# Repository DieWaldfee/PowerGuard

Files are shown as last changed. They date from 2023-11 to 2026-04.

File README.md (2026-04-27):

# PowerGuard
PowerGuard-Platine und Software zur Sicherheitsüberwachung einer Heizstabsteuerung

**zugehörige Repositories**<br>
- PowerGuard (dieses Repository)
- Heizstabsteuerung (Steuerungsplatine <a href="https://github.com/DieWaldfee/Heizstabsteuerung"> Link </a>)
- Heizstab_ioBroker (Ansteuerungs-Blockly - ein MQTT-Broker wird benötigt - Link)

**Funktion:** <br>
Der ESP32 steuert 2 Temperatursensoren (DS18B20) an und liest diese aus. Die beiden Sensoren sollen am höchsten Punkt des Pufferspeichers der Heizung angebracht werden, in dem auch der elektrische Heizstab eingeschraubt ist. 
Die beiden Werte werden einerseits verglichen und andererseits benutzt, um die Pufferspeichertemperatur zu überwachen. Liegt die Temperatur zu hoch, dann ist zu viel Energie im Pufferspeicher und vermutlich ist der Heizstab dafür ursächlich -> der Heizstabsteuerung wird der Strom abgeschalten. Dies stellt eine unabhängige Sicherungsfunktion dar, das jedweder Fehler im Heizstabsystem behandelt und die Anlage in den sicheren Zustand überführt (d.h. aus).<p>
Der PowerGuard hat 2 Möglichkeiten dies zu tun: <br>
(1) die 5V Versorgung des ESP32 der Heizstabsteuerung abzuschalten -> die Relais werden nicht mehr angesteuert - unabhängig vom Fehlerbild. <br>
(2) die 12V Versorgungsspannung der Lastschaltrelais (SSR siehe Heizstabsteuerung) wird abgeschaltet -> die Heizstabsteuerung bleibt aktiv, kann aber nichts mehr schalten. <p>
Die Kommunikation mit dem ESP32 wird über WiFi abgewickelt und über das Protokoll MQTT umgesetzt. Es stehen mehrere Befehle zur Verfügung, die ebenfalls via MQTT an den ESP gesendet werden kann. Neben "restart" / "reboot" (führt zu einem Neustart des ESP32) kann die ganze Konfiguration und der debug-Level angepasst werden. Alle Anpassungen sind nach einem Neustart verloren, da diese nicht permanent gespeichert werden. Befehle werden unter der MQTT-Hierarchie in folgendem Ort empfangen: `SmartHome/Keller/Heizung/ESP32_PowerGuard/command` (MQTT_SERIAL_RECEIVER_COMMAND)

**Entwicklungsumgebungen:** <br>
Die aktuelle Software (V2.x) für den ESP32 wird mit **PlatformIO** entwickelt (z. B. in VS Code mit dem PlatformIO-Plugin). Die Konfiguration des Projekts befindet sich in der Datei `platformio.ini`; Compilieren und Flashen erfolgen direkt über PlatformIO.<br>
Die historische Erstversion (V1.0) wurde in der **Arduino-IDE** erstellt und ist im Unterordner `V1.0/` archiviert.<br>
Die Platine (PCB) habe ich in Eagle von AutoCAD modelliert. Für Maker gibt es eine kostenfreie Version. Die CAM-Daten (PCB-Produktionsdaten), sowie die BOM (Stückliste) sind ebenfalls aus Eagle ausgegeben.
Eine Übersichtsversion der Platine ist mit Fritzing umgesetzt und enthält auch einige Notizen zur Pinbelegung.<br>

**benötigte Umgebung:** <br>
- ioBroker zur Ansteuerung (geht natürlich auch mit anderen SmartHome-Systemen, solange diese MQTT sprechen können)
- ioBroker MGTT-Adapter
- MQTT-Broker: z.B. mosquitto unter Linux/Debian/Raspian...
- 230V Stromversorgung oder alternativ eine 5V Versorgung über z.B. ein USB-Ladegerät (muss 2 ESP32 sicher versorgen können -> 2A reicht völlig aus) oder über die Schraubklemmen anderweitig versorgt.

### Abhängigkeiten (PlatformIO / `platformio.ini`):
OneWire:_______________PaulStoffregen/OneWire (git-master) – v2.3.7 inkompatibel mit ESP-IDF 5.x; v2.3.8 buggy<br>
DallasTemperature:_____milesburton/DallasTemperature v4.0.4<br>
PubSubClient:__________knolleary/PubSubClient v2.8<br>
WiFi.h / esp_task_wdt:_Espressif Arduino-Framework (via pioarduino platform-espressif32)<br>

### Board / Plattform (PlatformIO):
platform: pioarduino platform-espressif32 v55.03.38-1 (ESP-IDF 5.x)<br>
board: esp32dev<br>
framework: arduino<br>

**Hardware-Version (PCB V1.0 vs. V2.0):**<br>
In `platformio.ini` kann die Hardware-Version über ein Build-Flag gesetzt werden:<br>
```
build_flags = -DHARDWARE_VERSION=2   ; für PCB V2.0 (mit MSG-LED an Pin 22)
```
Ohne Build-Flag wird V1.0-Verhalten angenommen (kein MSG-LED, Blink auf OK-LED).<br>

| PIN | V1.0 | V2.0 |
|-----|---|---|
| 19  | LED OK (grün) | LED OK (grün) |
| 22  | – | LED MSG (gelb) |
| 23  | LED ERROR (rot) | LED ERROR (rot) |
| 25  | DS18B20 OneWire Bus | DS18B20 OneWire Bus |
| 32  | PHASE 5V (Heizstabsteuerung) | PHASE 5V (Heizstabsteuerung) |
| 18  | PHASE 12V (SSR-Relaisversorgung) | PHASE 12V (SSR-Relaisversorgung) |

**aktuelle Versionen:** <br>
- ESP-Software    V2.x (PlatformIO, `src/PowerGuard.cpp`)
- ESP-Software    V1.0 (Arduino IDE, archiviert in `V1.0/PowerGuard.ino`)
- PCB (Eagle) 	   V2.0
- CAM             V1.0
- BOM             V1.0
- Fritzing		      V1.1
 
Fokus der PCB V2.0 ist die Platine mit über einen PCB-Hersteller umzusetzen.
Die CAM-Datei ist passend für https://jlcpcb.com. Stand 03.11.2023 ist die Platine für 2$ (5 St.) bestellbar.
In der BOM findet sich die Stückliste für die Bestückung wieder.



Zugehöriges Projekt: https://github.com/users/DieWaldfee/projects/1

**Installation:**
* Zugangsdaten in `/src/secrets.h` eintragen (Hostname, WLAN-SSID, WLAN-Passwort, MQTT-Server, MQTT-Port, MQTT-User, MQTT-Passwort)
* Hardware-Version in `platformio.ini` als Build-Flag setzen (`-DHARDWARE_VERSION=2` für PCB V2.0, weglassen für V1.0)
* MQTT-Pfade sind in `src/PowerGuard.cpp` als `#define` hinterlegt und können dort angepasst werden<br>
&nbsp;&nbsp;&nbsp;
* Debug-Level kann via MQTT-Befehl `debug=0` … `debug=3` zur Laufzeit gesetzt werden (0 = Boot only; 1 = Basic; 2 = Advanced; 3 = Absolut); alternativ im Quellcode in Zeile 14 von `src/PowerGuard.cpp`
* ESP-Software wird über PlatformIO compiliert und auf das „ESP32 Dev Kit V4" geflasht.
* Platine entweder via Eagle an PCB-Hersteller übermitteln, oder das fertige CAM-File über die Anbieter-Webseite senden. (z.B. an https://jlcpcb.com)
* Platine bestücken + ESP und Level-Shifter (3.3V <-> 5V) aufsetzen.
* Relais anschließen.
* 12V Versorgung der Heizstabsteuerung wird über LED-Treiber realisiert.

### MQTT-Steuerbefehle

Befehle werden auf dem Topic **`SmartHome/Keller/Heizung/ESP32_PowerGuard/command`** empfangen.<br>
Bestätigungen erscheinen auf **`SmartHome/Keller/Heizung/ESP32_PowerGuard/ac`**.

| Befehl | Beschreibung | Antwort (ac-Topic) |
|---|---|---|
| `Test` | Verbindungstest | `Test OK` |
| `debug=0` … `debug=3` | Debug-Level setzen (0=Boot only, 1=Basic, 2=Advanced, 3=Absolut) | `debug=X umgesetzt` |
| `panicMode=0` | Panic-Modus zurücksetzen; Heizstabsteuerung neu starten (wenn thermalLimit=0) | `panicMode=0 umgesetzt` |
| `panicMode=1` | Panic-Abschaltung auslösen (5V + 12V aus) | `panicMode=1 umgesetzt` |
| `hardwareError=0` | Hardware-Fehler-Flag zurücksetzen | `hardwareError=0 umgesetzt` |
| `hardwareError=1` | Hardware-Fehler setzen → Panic-Abschaltung | `hardwareError=1 umgesetzt` |
| `thermalLimit=0` | Thermisches Limit zurücksetzen; Heizstabsteuerung neu starten (wenn panicMode=0 und hardwareError=0) | `thermalLimit=0 umgesetzt` |
| `thermalLimit=1` | Thermische Abschaltung auslösen (12V aus) | `thermalLimit=1 umgesetzt` |
| `tempLimit=<Wert>` | Abschalttemperatur 12V [°C] (Standard: 90,0) | `tempLimit=<Wert> umgesetzt` |
| `tempMaxLimit=<Wert>` | Panic-Abschalttemperatur 5V+12V [°C] (Standard: 95,0) | `tempMaxLimit=<Wert> umgesetzt` |
| `tempReconnect=<Wert>` | Wiedereinschalttemperatur [°C] (Standard: 80,0) | `tempReconnect=<Wert> umgesetzt` |
| `deltaT=<Wert>` | Max. zulässige Differenz zwischen den beiden Sensoren [K] (Standard: 2,0) | `deltaT=<Wert> umgesetzt` |
| `minTemp=<Wert>` | Untere Plausibilitätsgrenze [°C] (Standard: 10,0) | `minTemp=<Wert> umgesetzt` |
| `maxTemp=<Wert>` | Obere Plausibilitätsgrenze [°C] (Standard: 100,0) | `maxTemp=<Wert> umgesetzt` |
| `restart` oder `reboot` | ESP32 neu starten (Ausgänge werden vorher abgeschaltet) | `reboot in einer Sekunde!` |

> **Hinweis:** Alle Parameteränderungen sind flüchtig und gehen nach einem Neustart verloren.

### MQTT-Statustopics (veröffentlicht, alle 60 s)

Basis-Pfad: `SmartHome/Keller/Heizung/ESP32_PowerGuard/`

| Topic (relativ zum Basis-Pfad) | Inhalt | Retain |
|---|---|---|
| `status` | Online-Status: `true` / `false` (LWT) | ja |
| `ac` | Befehlsbestätigungen | nein |
| `error` | Fehlermeldungen / Reconnect-Infos | ja |
| `Temperatur/0/JSON` | Sensor 0 komplett als JSON | nein |
| `Temperatur/0/Temperatur` | Temperatur Sensor 0 [°C] | nein |
| `Temperatur/0/ID` | Sensor-Index 0 | nein |
| `Temperatur/0/Adresse` | 1-Wire-Adresse Sensor 0 | nein |
| `Temperatur/0/Ort` | Ortsbezeichnung Sensor 0 | nein |
| `Temperatur/1/…` | Gleiche Subtopics für Sensor 1 | nein |
| `state/JSON` | Systemzustand komplett als JSON | nein |
| `state/panicMode` | Panic-Mode Flag (0/1) | nein |
| `state/thermalLimit` | Thermal-Limit Flag (0/1) | nein |
| `state/hardwareError` | Hardware-Fehler Flag (0/1) | nein |
| `state/lastError` | Letzter Fehler als Klartext | nein |
| `state/WiFi_Signal_Strength` | WiFi-Signalstärke [dBm] | nein |
| `state/WiFi_IP_Adress` | IP-Adresse | nein |
| `state/WiFi_MAC_Adress` | MAC-Adresse | nein |
| `config/JSON_0` | Konfigurationsparameter als JSON | nein |

**Bezugsquellen:**
* Platinennetzteil AC-05-3    <a href="https://www.azdelivery.de/products/copy-of-220v-zu-5v-mini-netzteil"> AZ-Delivery </a>
* Levelshifter (3.3V <-> 5V)  <a href="https://www.amazon.de/RUNCCI-YUN-Pegelwandler-Converter-BiDirektional-Mikrocontroller/dp/B082F6BSB5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"> Amazon </a>
* Relais <a href="https://www.amazon.de/gp/product/B0B5816YJ7/ref=ppx_yo_dt_b_search_asin_image?ie=UTF8&th=1"> Amazon </a> oder <a href="https://www.az-delivery.de/products/relais-modul"> AZ Delivery </a>
* 12V LED-Treiber als Schaltspannung der SSR-Relais  <a href="https://www.amazon.de/gp/product/B082NLNCSB/ref=ppx_yo_dt_b_search_asin_image?ie=UTF8&psc=1"> Amazon </a>
* JST-Buchse <a href="https://www.amazon.de/gp/product/B0B2R99X99/ref=ppx_yo_dt_b_search_asin_title?ie=UTF8&psc=1"> Amazon </a>
* Klemmbuchse <a href="https://www.amazon.de/gp/product/B087RN8FDZ/ref=ppx_yo_dt_b_search_asin_title?ie=UTF8&th=1"> Amazon </a>
* Widerstände 4,7kOhm, 220 Ohm, 330 Ohm, Led grün, gelb und rot Amazon / eBay / Conrad...
* Temperatursensoren DS18B20 <a href="https://www.az-delivery.de/products/2er-set-ds18b20-mit-3m-kabel"> AZ Delivery </a>

**fertige Platine:**

grafik

grafik
(oberes Relais steuert +5V -> Heizstabsteuerung; unteres Relais steuert die 12V für die SSR-40-DA Lastschaltrelais)

**Haftungsausschluss**<br>
Deutsch: Dieses Projekt arbeitet mit Netzspannung (220 V) und darf ausschließlich von qualifiziertem Fachpersonal aufgebaut, installiert und betrieben werden. Durch die anliegende Spannung besteht Lebensgefahr! Fehler in Schaltung oder Software können zu Sachschäden (z. B. an Gebäude oder Heizung) oder zu gefährlichen Situationen für Leib und Leben führen. Nutzung auf eigene Gefahr – jegliche Haftung wird ausgeschlossen.
<br>
English: This project operates with mains voltage (220 V) and must only be assembled, installed, and operated by qualified professionals. The present voltage poses a risk of fatal electric shock! Errors in circuitry or software may cause property damage (e.g., to buildings or heating systems) or create life-threatening situations. Use at your own risk – any liability is disclaimed.

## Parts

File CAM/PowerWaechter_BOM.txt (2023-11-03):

Stückliste PowerGuard 03.11.2023 15:11

Part    Value                    Device                   Package                  Description                                         AVAILABILITY CHECK_PRICES                                                                     DESCRIPTION                                                MF                                                                                         MP                MPN           OC_FARNELL OC_NEWARK PACKAGE POPULARITY PRICE PURCHASE-URL                                           SNAPEDA_LINK SPICEPREFIX                                                                      
CON1    JST-XH-03                JST-XH-03                JST-XH-03                                                                                                                                                                                                                                                                                                                                                                                                                                                                                                                                                           
CON2    JST-XH-03                JST-XH-03                JST-XH-03                                                                                                                                                                                                                                                                                                                                                                                                                                                                                                                                                           
CON3                             WAGO-500-2               WAGO-500-2               WAGO SCREW CLAMP                                                                                                                                                                                                                                                                                                          237-102       unknown    70K9898           32                                                                                                                                                                    
CON4                             WAGO-500-2               WAGO-500-2               WAGO SCREW CLAMP                                                                                                                                                                                                                                                                                                          237-102       unknown    70K9898           32                                                                                                                                                                    
JP1                              JP4E                     JP4                      JUMPER                                                                                                                                                                                                                                                                                                                                                               15                                                                                                                                                                    
LED1    rot                      LED3MM                   LED3MM                   LED                                                                                                                                                                                                                                                                                                                                                                  97                                                                                                                                                                    
LED2    grün                     LED3MM                   LED3MM                   LED                                                                                                                                                                                                                                                                                                                                                                  97                                                                                                                                                                    
LED3    gelb                     LED3MM                   LED3MM                   LED                                                                                                                                                                                                                                                                                                                                                                  97                                                                                                                                                                    
LS_SSR1 LEVELSHIFTER             LEVELSHIFTER             LEVELSHIFTER             Logic Level Converter - Bi-Direc Check availability In Stock                                                                                       BSS138 Logic-Level Translator Interface Evaluation Board  SparkFun                                                                                   BOB-12009                                            None               None  https://pricing.snapeda.com/search?q=BOB-12009&ref=eda                                                                                               
POWER1  AC-05-3                  AC-05-3                  AC-05-3                  AC-05-3                                                                                                                                                                                                                                                                                                                                                                                                                                                                                                                                    
R1      220                      R_10MM0207/10            0207/10                  RESISTOR, European symbol                                                                                                                                                                                                                                                                                                                                            81                                                                                   R                                                                                
R2      330                      R_10MM0207/10            0207/10                  RESISTOR, European symbol                                                                                                                                                                                                                                                                                                                                            81                                                                                   R                                                                                
R3      220                      R_10MM0207/10            0207/10                  RESISTOR, European symbol                                                                                                                                                                                                                                                                                                                                            81                                                                                   R                                                                                
R4      4.7 k                    R_10MM0207/10            0207/10                  RESISTOR, European symbol                                                                                                                                                                                                                                                                                                                                            81                                                                                   R                                                                                
U1      ESP32-DEV-KIT-V4         ESP32-DEV-KIT-V4         ESP32-DEV-KIT-V4         ESP32-DEVKITC Check availability                    In Stock     https://www.snapeda.com/parts/ESP32-DEVKITC/Espressif+Systems/view-part/?ref=eda  ESP32-WROOM-32UE series Transceiver                        802.11 b/g/n (Wi-Fi, WiFi, WLAN), Bluetooth ® Smart Ready 4.x Dual Mode Evaluation Board  Espressif Systems ESP32-DEVKITC                              None             None                                                                https://www.snapeda.com/parts/ESP32-DEVKITC/Espressif+Systems/view-part/?ref=snap

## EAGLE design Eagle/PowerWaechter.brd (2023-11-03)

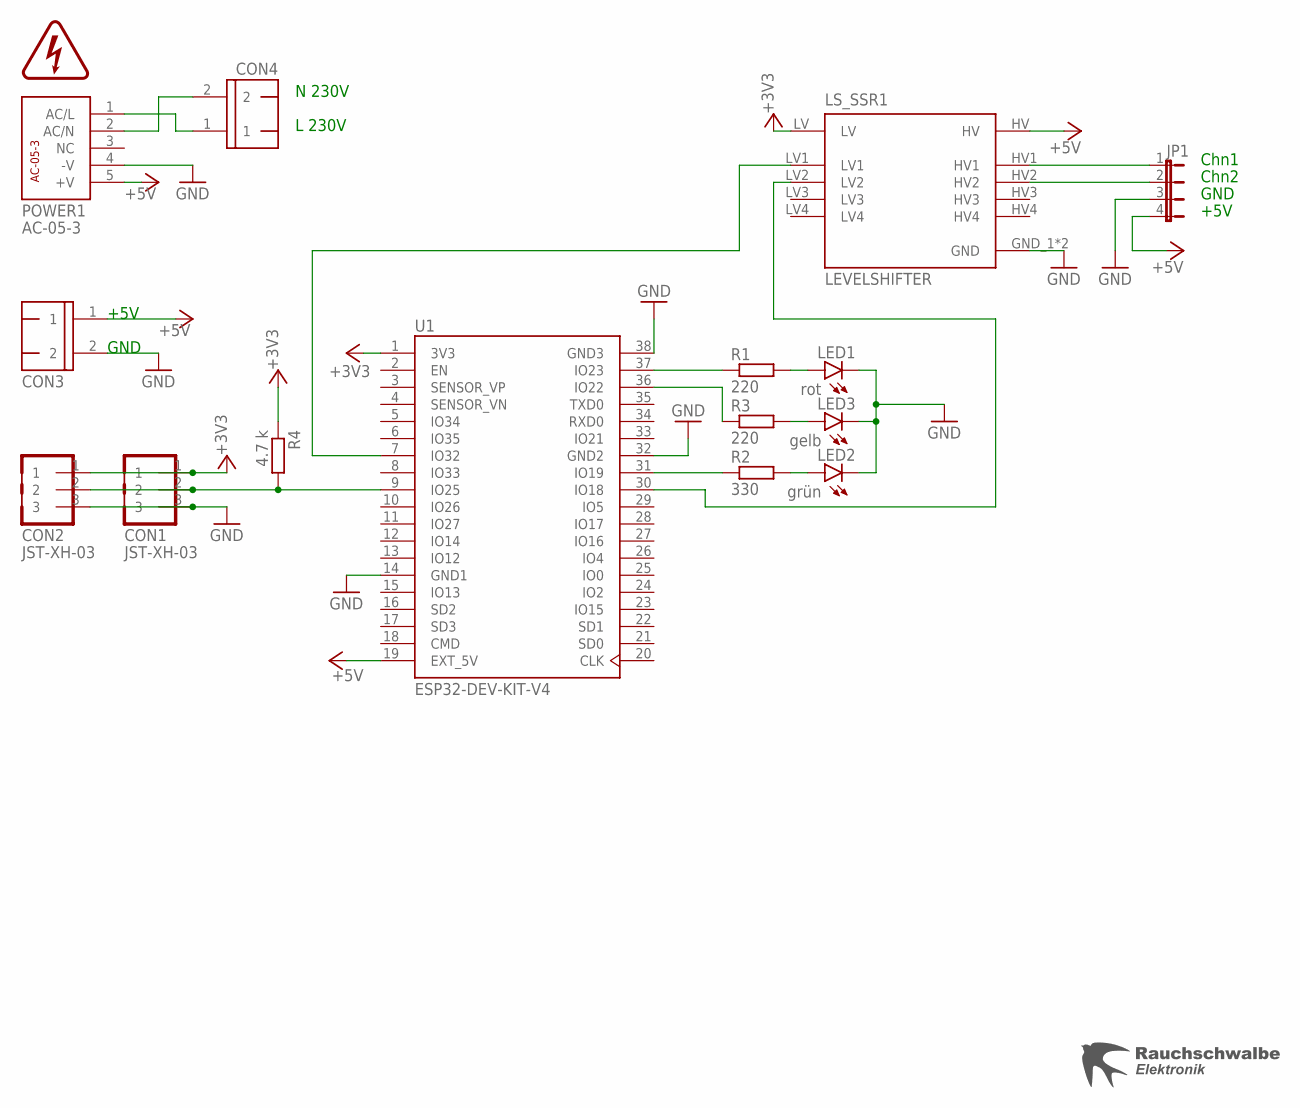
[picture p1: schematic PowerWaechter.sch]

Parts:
CON1, CON2: JST-XH-03
CON3, CON4: WAGO-500-2
JP1: JP4E; JP4
LED1: rot; LED3MM
LED2: grün; LED3MM
LED3: gelb; LED3MM
LS_SSR1: LEVELSHIFTER
POWER1: AC-05-3
R1, R3: 220; 0207/10
R2: 330; 0207/10
R4: 4.7 k; 0207/10
U1: ESP32-DEV-KIT-V4
U$1: WARNLABLE_BLITZ_KLEIN
U$2: LOGO_RAUCHSCHWALBE_KLEIN

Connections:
+3V3: CON1.1, CON2.1, LS_SSR1.LV, R4.1, U1.1 (3V3)
+5V: CON3.1, JP1.4, LS_SSR1.HV, POWER1.5 (+V), U1.19 (EXT_5V)
GND: CON1.3, CON2.3, CON3.2, JP1.3, LED1.K (C), LED2.K (C), LED3.K (C), LS_SSR1.GND_1 (GND), LS_SSR1.GND_2 (GND), POWER1.4 (-V), U1.14 (GND1), U1.32 (GND2), U1.38 (GND3)
unnamed: R1.1, U1.37 (IO23)
unnamed: LED3.A, R3.2
unnamed: R2.1, U1.31 (IO19)
unnamed: LED1.A, R1.2
unnamed: LED2.A, R2.2
unnamed: R3.1, U1.36 (IO22)
unnamed: LS_SSR1.LV1, U1.7 (IO32)
unnamed: CON1.2, CON2.2, R4.2, U1.9 (IO25)
unnamed: LS_SSR1.LV2, U1.30 (IO18)
unnamed: JP1.1, LS_SSR1.HV1
unnamed: JP1.2, LS_SSR1.HV2
PHASE_L: CON4.1, POWER1.1 (AC/L)
PHASE_N: CON4.2, POWER1.2 (AC/N)

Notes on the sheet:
GND
+5V
Chn1
Chn2
L 230V
N 230V

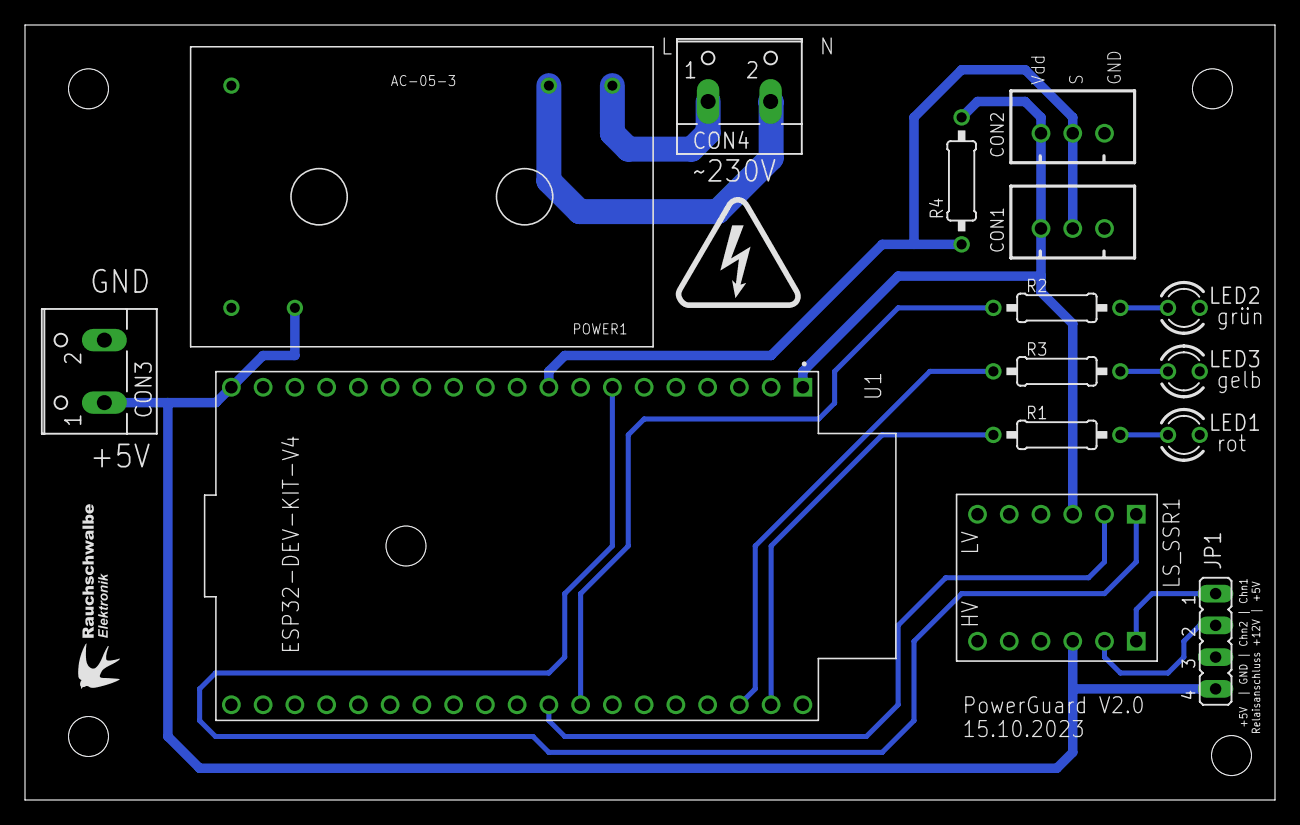
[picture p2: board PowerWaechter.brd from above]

Board: 2 copper layers, 100.0 x 62.0 mm, 17 parts (0 on the bottom side), 16 nets.

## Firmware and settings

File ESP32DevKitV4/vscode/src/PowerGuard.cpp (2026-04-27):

//https://beelogger.de/sensoren/temperatursensor-ds18b20/ für Pinning und Anregung
#include <OneWire.h>
#include <DallasTemperature.h>
#include <WiFi.h>
#include <WiFiClient.h>
#include <PubSubClient.h>
#include <esp_task_wdt.h>
#include "secrets.h"

#define LED_ERROR 23
#define LED_MSG 22
#define LED_OK 19
#define ONE_WIRE_BUS 25
static byte debug = 0;
static String lastError = "";

//Sicherheitsfunktionen
int volatile hardwareError = 0; // Indikator, ob ein Sensordefekt erkannt wurde.
int volatile thermalLimit = 0;  // Indikator, das die maximale Temperatur am Top-Sensor. Phasen werden abgeschalten.
int volatile panicMode = 0;     // Indikator für die Zwangsabschaltung - ab jetzt wird nichts mehr zugeschaltet

//Schaltausgaenge für Phase 1-3 und Luefter
#define PHASE_5V 32             // Steuerpin für Phase 5V Versorgung zum ESP32 Heizstabsteuerung
#define PHASE_12V 18            // Steuerpin für Phase 12V Versorgung zum ESP32 Heizstabsteuerung

// Definition der Zugangsdaten WiFi
WiFiClient myWiFiClient;

//Definition der Zugangsdaten MQTT
#define MQTT_CLIENTID "ESP32_PowerGuard" //Name muss eineindeutig auf dem MQTT-Broker sein!
#define PG_MQTT_KEEPALIVE 90
#define PG_MQTT_SOCKETTIMEOUT 30
#define MQTT_SERIAL_PUBLISH_STATUS "SmartHome/Keller/Heizung/ESP32_PowerGuard/status"
#define MQTT_SERIAL_RECEIVER_COMMAND "SmartHome/Keller/Heizung/ESP32_PowerGuard/command"
#define MQTT_SERIAL_PUBLISH_DS18B20 "SmartHome/Keller/Heizung/ESP32_PowerGuard/Temperatur/"
#define MQTT_SERIAL_PUBLISH_STATE "SmartHome/Keller/Heizung/ESP32_PowerGuard/state/"
#define MQTT_SERIAL_PUBLISH_CONFIG "SmartHome/Keller/Heizung/ESP32_PowerGuard/config/"
#define MQTT_SERIAL_PUBLISH_BASIS "SmartHome/Keller/Heizung/ESP32_PowerGuard/"
DeviceAddress myDS18B20Address;
unsigned long MQTTReconnect = 0;
#define MQTT_QUEUEDEPTH 50                // Tiefe der MQTT-Queue - 50 Botschaften
#define QUEUEMAXWAITTIME 3                // Wartezeit für das Senden in eine Queue - danach Error!
struct MqttJob {                          // Struktur der MQTT-Queue
  char topic[128];                        // topic:   Topic auf den die Botschaft gesendet werden soll -> 180 Zeichen lang
  char payload[256];                      // payload: Botschaft, die an das Topic gesendet werden soll. -> 256 Zeichen max.
  bool retain;                            // retain:  true, wenn die Botschaft im Broker gespeichert bleibt und false, wenn
};                                        // nur die angemeldeten User die Botschaft erhalten - diese dann vergessen wird.
PubSubClient mqttClient(myWiFiClient);
static QueueHandle_t mqttQueue;           // Queuedefinition für die MQTT-Queue
static TaskHandle_t hmqtt;                // handler für den MQTT-Sender-Task

// Anzahl der angeschlossenen DS18B20 - Sensoren
int DS18B20_Count = 0;            //Anzahl der erkannten DS18B20-Sensoren
//Sensorsetting (Ausgabe im Debugmodus (debug = 3) auf dem serial Monitor)
float volatile temp1 = 0.0;       //Sensor in Slot 2
float volatile temp2 = 0.0;       //Sensor in Slot 3
float tempLimit = 90.0;           //Ab dieser Temperatur wir 12V abgeschalten und thermalLimit = 1
float tempReconnect = 80.0;       //Ab dieser Temperatur thermalLimit = 0 und panicMode = 0 zurückgesetzt -> ESP32 Heizstabsteuerung boot neu nach PanicMode / bei thermalLimit wird kurz 5V abgeschaltet und der Neustart erzwungen..
float tempMaxLimit = 95.0;        //Panik-Abschaltung ab dieser Temperatur = 5V und 12V abschalten und thermalLimit = 1 & panicMode = 1
float deltaT = 2.0;               //Limit des Betrags von Differenz zwischen tempTop1 tempTop2 (|tempTop1-tempTop2|)
float minTemp = 10.0;             //untere Plausibilitätsgrenze für Temperatursignale. Bei Unterschreitung => Notabschaltung, da ggf. Sensor defekt
float maxTemp = 100.0;            //obere Plausibilitätsgrenze für Temperatursignale. Bei Überschreitung => Notabschaltung, da ggf. Sensor defekt
int volatile tempTSensorFail = 0; //Fehlercounter zur Temperaturmessung - Resilienz gegen gelegentliche Fehlauswertungen der Temperatursensoren
int maxTSensorFail = 3;           //maximal zulässige, hinereinander folgende Sensorfehler - danach panicStop
float DS18B20_minValue = -55.0;   //unterster Messwert im Messbereich [°C]
float DS18B20_maxValue = 125.0;   //unterster Messwert im Messbereich [°C]
#define DS18B20_RESOLUTION 10     // 9bit: ±0.5°C @ 93.75ms; 10bit: ±0.25°C @ 187.5ms; 11bit: ±0.125°C @ 375ms; 12bit: ±0.0625°C @ 750ms
#define DS18B20_DELAY 20          // Wartezeit nach angetriggerter Messung [ms]

//Initialisiere OneWire und Thermosensor(en)
OneWire oneWire(ONE_WIRE_BUS);
DallasTemperature myDS18B20(&oneWire);

//Mutexdefinitionen
static SemaphoreHandle_t mutexTemp;
static SemaphoreHandle_t mutexTempSensor;
static SemaphoreHandle_t mutexStatus;
static SemaphoreHandle_t mutexMQTT;

#define MQTT_STATE_REFRESH 60000  // Intervall des MQTT-Status-Tasks: 60.000 Ticks = 60s

//TaskHandler zur Verwendung mit ESP watchdog
static TaskHandle_t htempSensor;
static TaskHandle_t hMQTTwatchdog;

//PreDefinition Funktionen
void panicStop(void);
void thermalStop(void);
void Heizstab_reboot(void);

//erforderliche Funtions-Prototypen
bool mqttPublishQueue(const char*, const char*, bool);
String formatDS18B20Address(const DeviceAddress addr);

//-------------------------------------
// Basisfunktion zum sicheren Reset
void safeReset() {
  Serial.println("ESP32 Reset wird vorbereitet...");
  // Guard: mutexMQTT existiert erst nach Mutex-Initialisierung in setup()
  // Ohne diese Prüfung: xSemaphoreTake(NULL) → Assert-Crash wenn safeReset()
  // aus mqttConnect() heraus aufgerufen wird, bevor setup() die Mutexe angelegt hat.
  if (mutexMQTT != nullptr) {
    Serial.println("MQTT Disconnect...");
    xSemaphoreTake(mutexMQTT, pdMS_TO_TICKS(1000));  // best-effort; kein assert - Reboot folgt
    mqttClient.disconnect();
    delay(50);
    Serial.println("Flush TCP-Buffer...");
    myWiFiClient.clear();
    delay(50);
    // bewusst kein xSemaphoreGive - blockiert alle MQTT-Ops anderer Tasks bis Reboot
  }
  Serial.println("ESP32 Reset!");
  ESP.restart();
}

//-------------------------------------
// Callback für MQTT
void mqttCallback(char* topic, byte* message, unsigned int length) {
  BaseType_t rc;
  String str;
  unsigned long mqttValue;
  String mqttMessage;
  String mqttTopicAC;
  byte tx_ac = 1;
  for (int i = 0; i < length; i++)
  {
    str += (char)message[i];
  }
  if (debug > 1) {
    Serial.print("Nachricht aus dem Topic: ");
    Serial.print(topic);
    Serial.print(". Nachricht: ");
    Serial.println(str);
  }
  //Test-Botschaften
  mqttTopicAC = MQTT_SERIAL_PUBLISH_BASIS;
  mqttTopicAC += "ac";
  if (str.startsWith("Test")) {
    if (debug) Serial.println("Test -> Test OK");
    mqttPublishQueue(mqttTopicAC.c_str(), "Test OK", false);
    tx_ac = 0;
  }
  // Mutex holen – schützt alle Schreibzugriffe auf volatile Status-Flags
  rc = xSemaphoreTake(mutexStatus, portMAX_DELAY);
  assert(rc == pdPASS);
  //debug-Modifikation
  if ((tx_ac) && (str.startsWith("debug="))) {
    if (str[6] >= '0' && str[6] <= '3') {
      debug = str[6] - '0';
      mqttPublishQueue(mqttTopicAC.c_str(), ("debug=" + String(debug) + " umgesetzt").c_str(), false);
      tx_ac = 0;
    }
  }
  //panicMode-Modifikation
  if ((tx_ac) && (str.startsWith("panicMode=0"))) {
    panicMode = 0;
    if (thermalLimit == 0) {
      rc = xSemaphoreGive(mutexStatus);  // panicStop/Heizstab_reboot nehmen mutex selbst
      assert(rc == pdPASS);
      Heizstab_reboot();
      rc = xSemaphoreTake(mutexStatus, portMAX_DELAY);
      assert(rc == pdPASS);
    }
    mqttPublishQueue(mqttTopicAC.c_str(), "panicMode=0 umgesetzt", false);
    tx_ac = 0;
  }
  if ((tx_ac) && (str.startsWith("panicMode=1"))) {
    panicMode = 1;
    mqttPublishQueue(mqttTopicAC.c_str(), "panicMode=1 umgesetzt", false);
    rc = xSemaphoreGive(mutexStatus);
    assert(rc == pdPASS);
    panicStop();
    rc = xSemaphoreTake(mutexStatus, portMAX_DELAY);
    assert(rc == pdPASS);
    tx_ac = 0;
  }
  //hardwareError-Modifikation
  if ((tx_ac) && (str.startsWith("hardwareError=0"))) {
    hardwareError = 0;
    mqttPublishQueue(mqttTopicAC.c_str(), "hardwareError=0 umgesetzt", false);
    tx_ac = 0;
  }
  if ((tx_ac) && (str.startsWith("hardwareError=1"))) {
    hardwareError = 1;
    mqttPublishQueue(mqttTopicAC.c_str(), "hardwareError=1 umgesetzt", false);
    rc = xSemaphoreGive(mutexStatus);
    assert(rc == pdPASS);
    panicStop();
    rc = xSemaphoreTake(mutexStatus, portMAX_DELAY);
    assert(rc == pdPASS);
    tx_ac = 0;
  }
  //thermalLimit-Modifikation
  if ((tx_ac) && (str.startsWith("thermalLimit=0"))) {
    if (thermalLimit == 1) {
      if ((panicMode == 0) && (hardwareError == 0)) {
        thermalLimit = 0;
        rc = xSemaphoreGive(mutexStatus);
        assert(rc == pdPASS);
        Heizstab_reboot();
        rc = xSemaphoreTake(mutexStatus, portMAX_DELAY);
        assert(rc == pdPASS);
      } else {
        thermalLimit = 0;
      }
    }
    mqttPublishQueue(mqttTopicAC.c_str(), "thermalLimit=0 umgesetzt", false);
    tx_ac = 0;
  }
  if ((tx_ac) && (str.startsWith("thermalLimit=1"))) {
    rc = xSemaphoreGive(mutexStatus);
    assert(rc == pdPASS);
    thermalStop();
    rc = xSemaphoreTake(mutexStatus, portMAX_DELAY);
    assert(rc == pdPASS);
    mqttPublishQueue(mqttTopicAC.c_str(), "thermalLimit=1 umgesetzt", false);
    tx_ac = 0;
  }
  //Float-Parameter via Lookup-Tabelle (prefix.length() verhindert Off-by-one-Bugs)
  struct FloatParam { const char* prefix; float* target; };
  static const FloatParam floatParams[] = {
    {"tempLimit=",     &tempLimit},
    {"deltaT=",        &deltaT},
    {"minTemp=",       &minTemp},
    {"maxTemp=",       &maxTemp},
    {"tempReconnect=", &tempReconnect},
    {"tempMaxLimit=",  &tempMaxLimit},
  };
  for (int i = 0; i < (int)(sizeof(floatParams) / sizeof(floatParams[0])) && tx_ac; i++) {
    String prefix = floatParams[i].prefix;
    if (str.startsWith(prefix)) {
      *floatParams[i].target = str.substring(prefix.length()).toFloat();
      mqttMessage = prefix + String(*floatParams[i].target) + " umgesetzt";
      if (debug > 2) Serial.println(mqttMessage);
      mqttPublishQueue(mqttTopicAC.c_str(), mqttMessage.c_str(), false);
      tx_ac = 0;
    }
  }
  if ((tx_ac) && ((str.startsWith("restart")) || (str.startsWith("reboot")))) {
    // Kein Mutex nötig: Callback wird von mqttSender aufgerufen, das mutexMQTT bereits hält
    mqttClient.publish(mqttTopicAC.c_str(), "reboot in einer Sekunde!");
    if (debug) Serial.println("für Restart: alles aus & restart in 1s!");
    digitalWrite(PHASE_5V, HIGH);
    digitalWrite(PHASE_12V, HIGH);
    digitalWrite(LED_OK, LOW);
    digitalWrite(LED_ERROR, HIGH);
    vTaskDelay(1000);
    if (debug) Serial.println("führe Restart aus!");
    safeReset();
  }
  // Mutex freigeben
  rc = xSemaphoreGive(mutexStatus);
  assert(rc == pdPASS);
}

//-------------------------------------
//Subfunktionen für MQTT-Status-Task
// MQTT DS18B20 Status senden
void printDS18B20MQTT() {
  String mqttTopic;
  String mqttJson;
  String mqttPayload;
  for (int i = 0; i < DS18B20_Count; i++) {
    //MQTT-Botschaften
    //JSON        
    myDS18B20.getAddress(myDS18B20Address, i);
    String adresse = formatDS18B20Address(myDS18B20Address);
    float tempVal = myDS18B20.getTempCByIndex(i);  // einmalig lesen – JSON und Topic bleiben konsistent
    mqttTopic = MQTT_SERIAL_PUBLISH_DS18B20 + String(i) + "/JSON";
    mqttJson = "{\"ID\":\"" + String(i) + "\"";
    mqttJson += ",\"Temperatur\":\"" + String(tempVal) + "\"";
    mqttJson += ",\"Adresse\":\"(" + adresse + ")\"";
    mqttJson += ",\"Ort\":\"Temperatur Sensor " + String(i) + "\"}";
    if (debug > 2) Serial.println("MQTT_JSON: " + mqttJson);
    mqttPublishQueue(mqttTopic.c_str(), mqttJson.c_str(), false);
    //Temperatur
    mqttTopic = MQTT_SERIAL_PUBLISH_DS18B20 + String(i) + "/Temperatur";
    mqttPayload = String(tempVal);
    mqttPublishQueue(mqttTopic.c_str(), mqttPayload.c_str(), false);
    if (debug > 2) Serial.print("MQTT ID: ");
    if (debug > 2) Serial.println(mqttPayload);
    //ID
    mqttTopic = MQTT_SERIAL_PUBLISH_DS18B20 + String(i) + "/ID";
    mqttPayload = String(i);
    mqttPublishQueue(mqttTopic.c_str(), mqttPayload.c_str(), false);
    if (debug > 2) Serial.print("MQTT Temperatur: ");
    if (debug > 2) Serial.println(mqttPayload);
    //Adresse
    mqttTopic = MQTT_SERIAL_PUBLISH_DS18B20 + String(i) + "/Adresse";
    mqttPublishQueue(mqttTopic.c_str(), adresse.c_str(), false);
    if (debug > 2) Serial.print("MQTT Adresse: ");
    if (debug > 2) Serial.println(adresse);
    //Ort
    mqttTopic = MQTT_SERIAL_PUBLISH_DS18B20 + String(i) + "/Ort";
    mqttPayload = "Temperatur Sensor " + String(i);
    mqttPublishQueue(mqttTopic.c_str(), mqttPayload.c_str(), false);
    if (debug > 2) Serial.print("MQTT Ort: ");
    if (debug > 2) Serial.println(mqttPayload);
  }
}
// MQTT Status Betrieb senden
void printStateMQTT() {
  String mqttTopic;
  String mqttJson;
  String mqttPayload;
  mqttTopic = MQTT_SERIAL_PUBLISH_STATE;
  mqttTopic += "JSON";
  mqttJson = "{\"panicMode\":\"" + String(panicMode) + "\"";
  mqttJson += ",\"thermalLimit\":\"" + String(thermalLimit) + "\"";
  mqttJson += ",\"hardwareError\":\"" + String(hardwareError) + "\"";
  mqttJson += ",\"lastError\":\"" + String(lastError) + "\"";
  mqttJson += ",\"WiFi_Signal_Strength\":\"" + ((WiFi.status() == WL_CONNECTED) ? String(WiFi.RSSI()) : String("--")) + "\"";
  mqttJson += ",\"WiFi_IP_Adress\":\"" + WiFi.localIP().toString() + "\"";
  mqttJson += ",\"WiFi_MAC_Adress\":\"" + WiFi.macAddress() + "\"}";
  if (debug > 2) Serial.println("MQTT_JSON: " + mqttJson);
  mqttPublishQueue(mqttTopic.c_str(), mqttJson.c_str(),false);
  //panicMode
  mqttTopic = MQTT_SERIAL_PUBLISH_STATE;
  mqttTopic += "panicMode";
  mqttPayload = String(panicMode);
  mqttPublishQueue(mqttTopic.c_str(), mqttPayload.c_str(),false);
  if (debug > 2) Serial.print("MQTT panicMode: ");
  if (debug > 2) Serial.println(mqttPayload);
  //thermalLimit
  mqttTopic = MQTT_SERIAL_PUBLISH_STATE;
  mqttTopic += "thermalLimit";
  mqttPayload = String(thermalLimit);
  mqttPublishQueue(mqttTopic.c_str(), mqttPayload.c_str(),false);
  if (debug > 2) Serial.print("MQTT thermalLimit: ");
  if (debug > 2) Serial.println(mqttPayload);
  //Hardware Error
  mqttTopic = MQTT_SERIAL_PUBLISH_STATE;
  mqttTopic += "hardwareError";
  mqttPayload = String(hardwareError);
  mqttPublishQueue(mqttTopic.c_str(), mqttPayload.c_str(),false);
  if (debug > 2) Serial.print("MQTT hardwareError: ");
  if (debug > 2) Serial.println(mqttPayload);
  //lastError
  mqttTopic = MQTT_SERIAL_PUBLISH_STATE;
  mqttTopic += "lastError";
  mqttPayload = String(lastError);
  mqttPublishQueue(mqttTopic.c_str(), mqttPayload.c_str(),false);
  if (debug > 2) Serial.print("LastError: ");
  if (debug > 2) Serial.println(mqttPayload);
  //WiFi Signalstärke
  mqttTopic = MQTT_SERIAL_PUBLISH_STATE;
  mqttTopic += "WiFi_Signal_Strength";
  mqttPayload = (WiFi.status() == WL_CONNECTED) ? String(WiFi.RSSI()) : String("--");
  mqttPublishQueue(mqttTopic.c_str(), mqttPayload.c_str(),false);
  if (debug > 2) Serial.print("WiFi Signalstärke: ");
  if (debug > 2) Serial.println(mqttPayload);
  //WiFi IP-Adresse
  mqttTopic = MQTT_SERIAL_PUBLISH_STATE;
  mqttTopic += "WiFi_IP_Adress";
  mqttPayload = WiFi.localIP().toString();
  mqttPublishQueue(mqttTopic.c_str(), mqttPayload.c_str(),false);
  if (debug > 2) Serial.print("WiFi IP-Adresse: ");
  if (debug > 2) Serial.println(mqttPayload);
  //WiFi MAC-Adresse
  mqttTopic = MQTT_SERIAL_PUBLISH_STATE;
  mqttTopic += "WiFi_MAC_Adress";
  mqttPayload = WiFi.macAddress();
  mqttPublishQueue(mqttTopic.c_str(), mqttPayload.c_str(),false);
  if (debug > 2) Serial.print("WiFi MAC-Adresse: ");
  if (debug > 2) Serial.println(mqttPayload);
}
// MQTT Config und Parameter senden
void printConfigMQTT() {
  String mqttTopic;
  String mqttJson;
  String mqttPayload;
  //Teil 1
  mqttTopic = MQTT_SERIAL_PUBLISH_CONFIG;
  mqttTopic += "JSON_0";
  mqttJson = "{\"tempLimit\":\"" + String(tempLimit) + "\"";
  mqttJson += ",\"tempMaxLimit\":\"" + String(tempMaxLimit) + "\"";
  mqttJson += ",\"tempReconnect\":\"" + String(tempReconnect) + "\"";
  mqttJson += ",\"deltaT\":\"" + String(deltaT) + "\"";
  mqttJson += ",\"minTemp\":\"" + String(minTemp) + "\"";
  mqttJson += ",\"maxTemp\":\"" + String(maxTemp) + "\"";
  mqttJson += ",\"thermalLimit\":\"" + String(thermalLimit) + "\"}";
  if (debug > 2) Serial.println("MQTT_JSON: " + mqttJson);
  mqttPublishQueue(mqttTopic.c_str(), mqttJson.c_str(),false);
}
// LED-Blik-MSG
void LEDblinkMSG() {
#if HARDWARE_VERSION >= 2
  digitalWrite(LED_MSG, HIGH);
  delay(150);
  digitalWrite(LED_MSG, LOW);
#else
  digitalWrite(LED_OK, HIGH);  // V1.0: kein MSG-LED, Blink auf OK-LED
  delay(150);
  digitalWrite(LED_OK, LOW);
#endif
}
//-------------------------------------
//MQTT-Status-Task
static void MQTTstate (void *args){
  BaseType_t rc;
  TickType_t ticktime;

  //ticktime initialisieren
  ticktime = xTaskGetTickCount();

  for (;;){                        // Dauerschleife des Tasks
    //Lesen der Temperaturen
    if (debug > 1) Serial.print("TickTime: ");
    if (debug > 1) Serial.print(ticktime);
    if (debug > 1) Serial.println(" | MQTT-Status-Task gestartet");
    rc = xSemaphoreTake(mutexMQTT, portMAX_DELAY);
    assert(rc == pdPASS);
    bool mqttConn = mqttClient.connected();
    xSemaphoreGive(mutexMQTT);
    if (mqttConn) {
      rc = xSemaphoreTake(mutexTempSensor, portMAX_DELAY);
      assert(rc == pdPASS);
      rc = xSemaphoreTake(mutexTemp, portMAX_DELAY);
      assert(rc == pdPASS);
        printDS18B20MQTT();
      rc = xSemaphoreGive(mutexTemp);
      assert(rc == pdPASS);
      rc = xSemaphoreGive(mutexTempSensor);
      assert(rc == pdPASS);

      rc = xSemaphoreTake(mutexStatus, portMAX_DELAY);
      assert(rc == pdPASS);
        printStateMQTT();
      rc = xSemaphoreGive(mutexStatus);
      assert(rc == pdPASS);

      printConfigMQTT();
    }

    if (debug > 1) Serial.println("Stack frei MQTTstate: " + String(uxTaskGetStackHighWaterMark(NULL) * 4) + " Bytes");

    // Task schlafen legen
    LEDblinkMSG();
    vTaskDelayUntil(&ticktime, MQTT_STATE_REFRESH);
  }
}

//-------------------------------------
//Subfunktionen für MQTTwatchdog-Task
// MQTT Verbindung herstellen (wird auch von setup verwendet!)
void mqttConnect () {
  int i = 0;
  int wifiWait = 0;
  while (WiFi.status() != WL_CONNECTED) {
    if (++wifiWait > 60) {
      Serial.println("WiFi nicht erreichbar! Reboot!!");
      safeReset();
    }
    Serial.print("W");
    esp_task_wdt_reset();
    delay(1000);
  }
  Serial.print("Verbindungsaufbau zu MQTT Server ");
  Serial.print(MQTT_SERVER);
  Serial.print(" Port ");
  Serial.print(MQTT_PORT);
  Serial.print(" wird aufgebaut ");
  while (!mqttClient.connected()) {
    Serial.print(".");
    if (mqttClient.connect(MQTT_CLIENTID, MQTT_USER, MQTT_PASSWORD, MQTT_SERIAL_PUBLISH_STATUS, 0, true, "false")) {
      mqttClient.publish(MQTT_SERIAL_PUBLISH_STATUS, "true", true);
      Serial.println("");
      Serial.print("MQTT verbunden!");
    }
    else {
      if (++i > 20) {
        Serial.println("MQTT scheint nicht mehr erreichbar! Reboot!!");
        safeReset();
      }
      Serial.print("fehlgeschlagen rc=");
      Serial.print(mqttClient.state());
      Serial.println(" erneuter Versuch in 5 Sekunden.");
      esp_task_wdt_reset();
      delay(5000);
    }
  }
  mqttClient.subscribe(MQTT_SERIAL_RECEIVER_COMMAND);
}
// MQTT Verbindungsprüfung 
void checkMQTTconnetion() {
  String mqttTopic;
  String mqttPayload;
  BaseType_t rc;
  if (!mqttClient.connected()) {
    if (debug) Serial.println("MQTT Server Verbindung verloren...");
    if (debug) Serial.print("Disconnect Errorcode: ");
    if (debug) Serial.println(mqttClient.state());  
    //Vorbereitung errorcode MQTT (https://pubsubclient.knolleary.net/api#state)
    mqttTopic = MQTT_SERIAL_PUBLISH_BASIS + String("error");
    mqttPayload = String(String(++MQTTReconnect) + ". reconnect: ") + String("; MQTT disconnect rc=" + String(mqttClient.state()));
    // 0	MQTT_CONNECTED	        Erfolgreich verbunden.
    // 1	MQTT_CONNECTION_TIMEOUT	Verbindung zum Broker hat zu lange gedauert (Timeout).
    // 2	MQTT_CONNECTION_LOST	  Verbindung ging verloren (nach dem Connect).
    // 3	MQTT_CONNECT_FAILED	    Verbindung konnte nicht hergestellt werden (Socket fehlerhaft).
    // 4	MQTT_DISCONNECTED	      Client ist aktuell nicht verbunden.
    // 5	MQTT_CONNECTED_FAILED	  Broker hat die Verbindung abgelehnt (z. B. Authentifizierung)
    //reconnect
    mqttConnect();
    //sende Fehlerstatus
    mqttPublishQueue(mqttTopic.c_str(), mqttPayload.c_str(), true);
    // thermalLimit nur zurücksetzen wenn beide Sensoren unter tempReconnect liegen
    rc = xSemaphoreTake(mutexTemp, portMAX_DELAY);
    assert(rc == pdPASS);
    float t1snap = temp1;
    float t2snap = temp2;
    rc = xSemaphoreGive(mutexTemp);
    assert(rc == pdPASS);
    rc = xSemaphoreTake(mutexStatus, portMAX_DELAY);
    assert(rc == pdPASS);
    if ((thermalLimit == 1) && (hardwareError == 0) &&
        (t1snap < tempReconnect) && (t2snap < tempReconnect)) {
      thermalLimit = 0;
      if (debug) Serial.println("MQTT-Reconnect: thermalLimit zurückgesetzt (Temp im Normalbereich).");
    } else if (thermalLimit == 1) {
      if (debug) Serial.println("MQTT-Reconnect: thermalLimit bleibt gesetzt (Temp noch zu hoch oder hardwareError).");
    }
    rc = xSemaphoreGive(mutexStatus);
    assert(rc == pdPASS);
    //reconnect zurückmelden
    mqttTopic = MQTT_SERIAL_PUBLISH_BASIS + String("ac");
    mqttPayload = String("MQTT reconnect durchgeführt!");
    mqttPublishQueue(mqttTopic.c_str(), mqttPayload.c_str(), false);
  }
}
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
void loop() {
  vTaskDelete(nullptr);
}

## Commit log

2023-11-03 V1.0.2 überführen
    [PowerGuard.fzz, PowerWaechter.brd, PowerWaechter.sch]
2023-11-03 v2.0.0 überführt
    [PowerGuard.fzz, PowerWaechter.brd, PowerWaechter.sch]
2023-11-04 Update README.md
    Bilder der fertigen Platine ergänzt
2023-12-11 Update PowerGuard.ino
    reboot bei Verlust der MQTT-Verbindung (20 erfolglose reconnect-Versuche)
2026-04-27 LED-Management for V1.0 & V2.0
2026-04-27 Revise README for ESP32 software and MQTT details
    Updated the README to reflect changes in the ESP32 software development environment and added details about MQTT commands and status topics.
